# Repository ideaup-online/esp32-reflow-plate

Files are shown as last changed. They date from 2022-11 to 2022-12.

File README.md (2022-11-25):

# Solder Reflow Plate Prototype

This is an ESP32 project for controlling a PCB-based solder reflow plate. The solder reflow plate used in this prototype was made using gerbers from [AfterEarthLTD's solder reflow plate](https://github.com/AfterEarthLTD/Solder-Reflow-Plate).

This project was created out of the need to assemble boards using solder reflow. I have some project ideas involving parts that have footprints that can't be soldered any other way.

I became aware of AfterEarthLTD's design after it was featured in a Great Scott! video on YouTube.

At the time I started this, ATmega328 chips are still not available and the code for the ATmega 4809 revision was not yet completed. So, I decided to send the gerbers for the ATmega 4809 revision to JLCPCB to be manufactured.

## Connecting the Solder Reflow Plate to Breadboard Prototype

The boards were populated with only the mosfet (with associated capacitor and zener diode) and the temp sensor (with associated capacitor). I also simply used a 1nF capacitor for both to reduce the number of parts I needed to purchase.

After that, an XT60 connector was soldered with pigtails to the pads for the barrel connector (I did not use the barrel connector). Leads were soldered for the positive side of the XT60, ground, 5V, the gate of the mosfet, and the output of the temp sensor. The positive side of the XT60 was picked up from the pad for the big capacitor that goes next to the barrel connector. Ground and 5V were picked up from the OLED connector through holes. The lead for the gate of the mosfet was soldered directly to the gate pin/pad of the mosfet (mosfet is installed on board). The temp sensor output was picked up from the ATmega 4809 footprint. The leads were terminated in a dupont connector for ease of breadboarding.

I powered all this from the XT60 using battery power of ~13.5V. That voltage was brought over to a breadboard where the rest of the components and the ESP32 were connected. 3.3V from the ESP32 is sent to the board via the 5V lead. This is fine because the only thing I populated that uses the 5V is the temp sensor and it is just as happy with 3.3V. The ground of the board is connected to the ground of the breadboard components. Finally, the gate and temp sensor voltage are passed to the breadboard via their leads.

The battery voltage is brought down to 5V with an XL4015 buck converter to power the ESP32 dev kit board. The ESP32 dev kit then provides 3.3V to everything else.

## Modifications to AfterEarthLTD's Design

Aside from the obvious of using an ESP32 instead of an ATmega, a couple of changes have been made.

The mosfet would not be turned on all the way by simply connecting the gate to one of the ESP32 GPIOs. The max output of 3.3V would not be sufficient. Therefore a DGD0215 gate driver has been used to drive the mosfet.

Also, the ESP32 ADC is not very linear. So, I opted to use a MAX11645 12-bit ADC and MCP1501-20 voltage reference. The LMT85 temp sensor tops out at around 1.9V on its output, so I chose the MCP1501-20 2.048V reference based on that.

Finally, an LED has been added to show when the heater is on (D1).

## 3D Printed Base

A simple 3D printed base has been created. This keeps the board from burning my desk when it gets hot. The STL file for it is here. It needs 4x M3x12 screws, 2x M3 washers, and 4x M3 nuts to assemble. I printed it in PETG on a Prusa Mini.

## Code

The code is not yet complete. The goal is to have the ability to have the board follow a solder reflow profile reasonably closely while being controlled and monitored via a web app running on the ESP32.

For now, there is a 128x64 OLED display just to monitor temperatures. It displays the value from the LMT85 as well as two K-type thermocouples attached via Adafruit MAX31855 breakout boards.

The current version of the code ensures that everything powers up without the heater coming on. The on-board button for GPIO0 can be used to turn on the heater (heater is only on while the button is pressed).

This readme will be updated as the code evolves.

## Should You Build One?

As of now, I would say no. My goal is to spin a new board based on the changes outlined above. I'd also like to try to make the working surface a bit larger than the current 50x70mm.

All that is going to take a little exploring and experimenting. That said, if you would like to do such exploration on your own, then by all means build this as is!

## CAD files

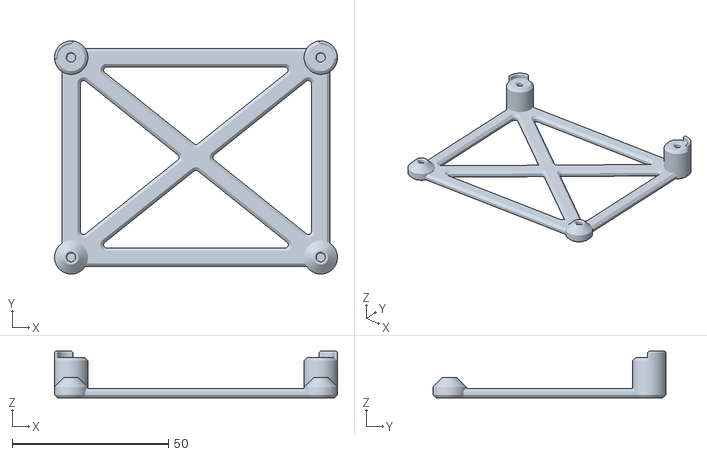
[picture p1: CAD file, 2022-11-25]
solder-reflow-base.stl
90.7 x 74.7 x 15.0

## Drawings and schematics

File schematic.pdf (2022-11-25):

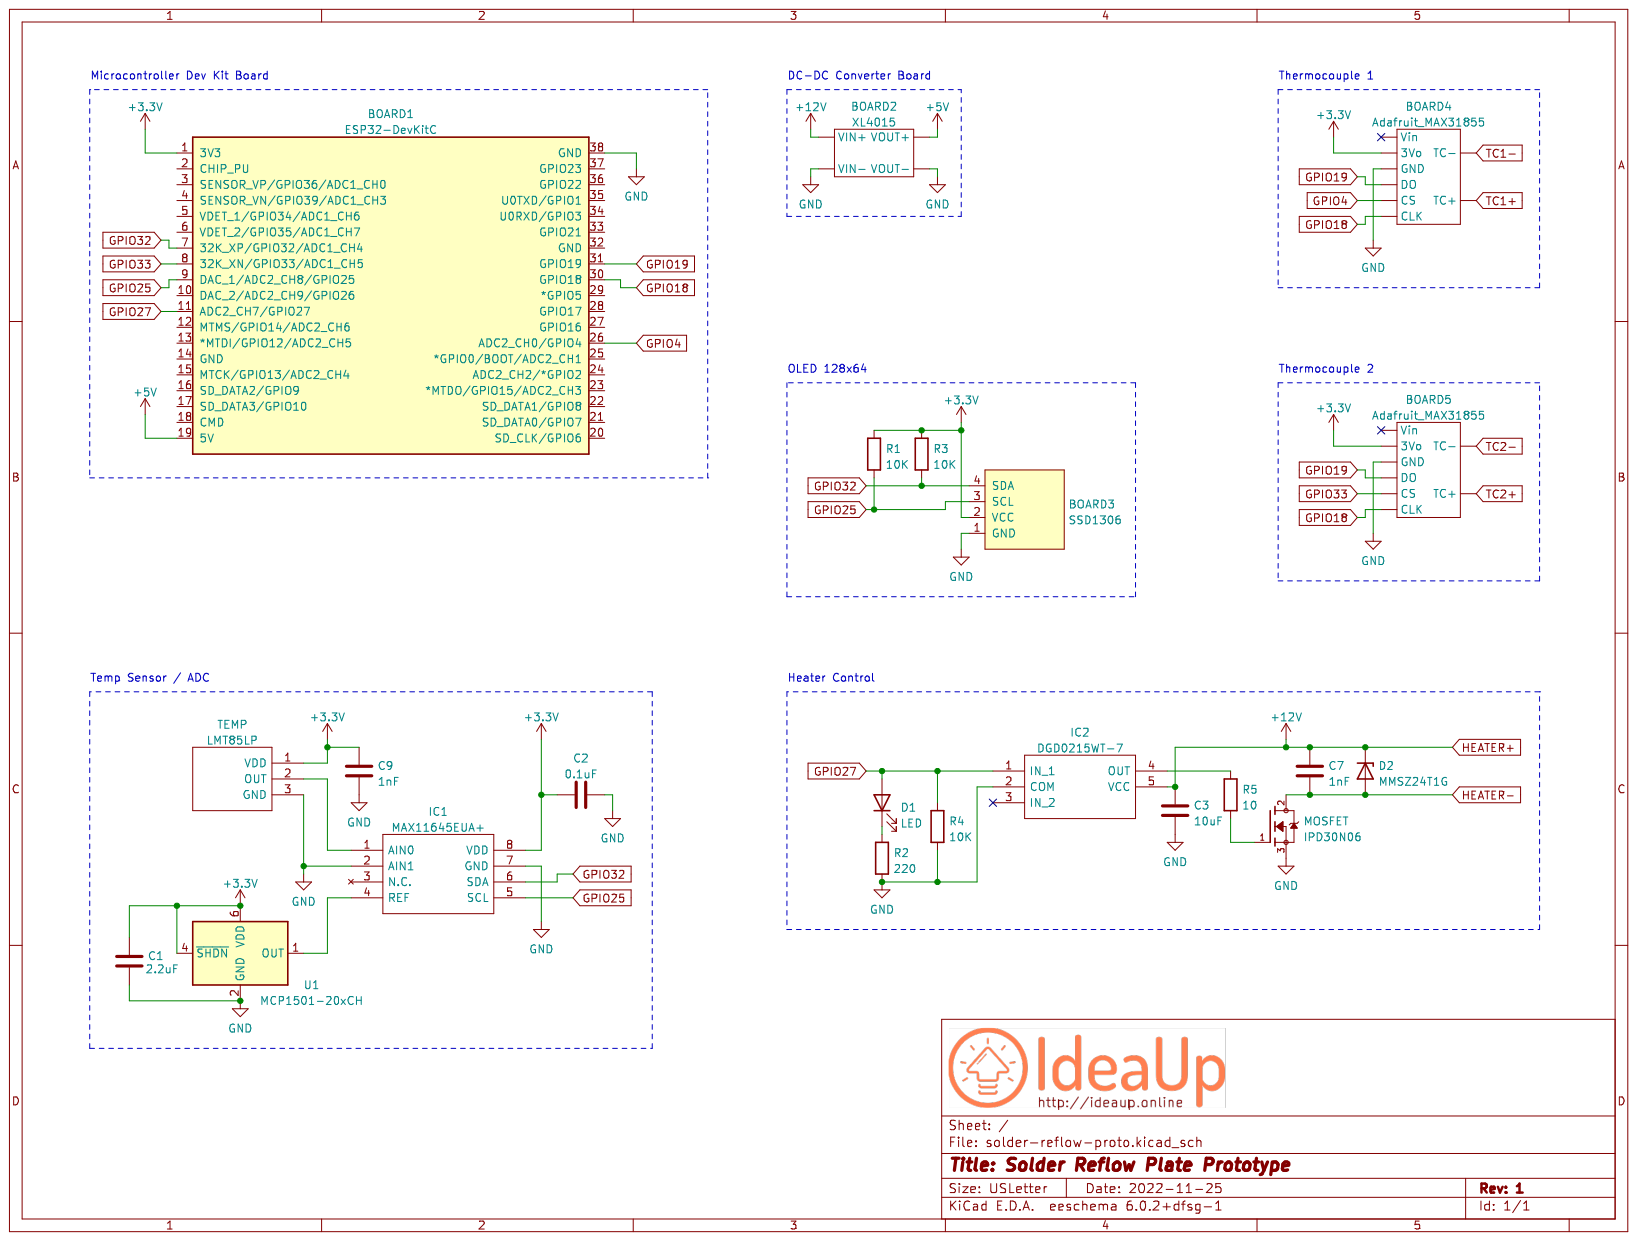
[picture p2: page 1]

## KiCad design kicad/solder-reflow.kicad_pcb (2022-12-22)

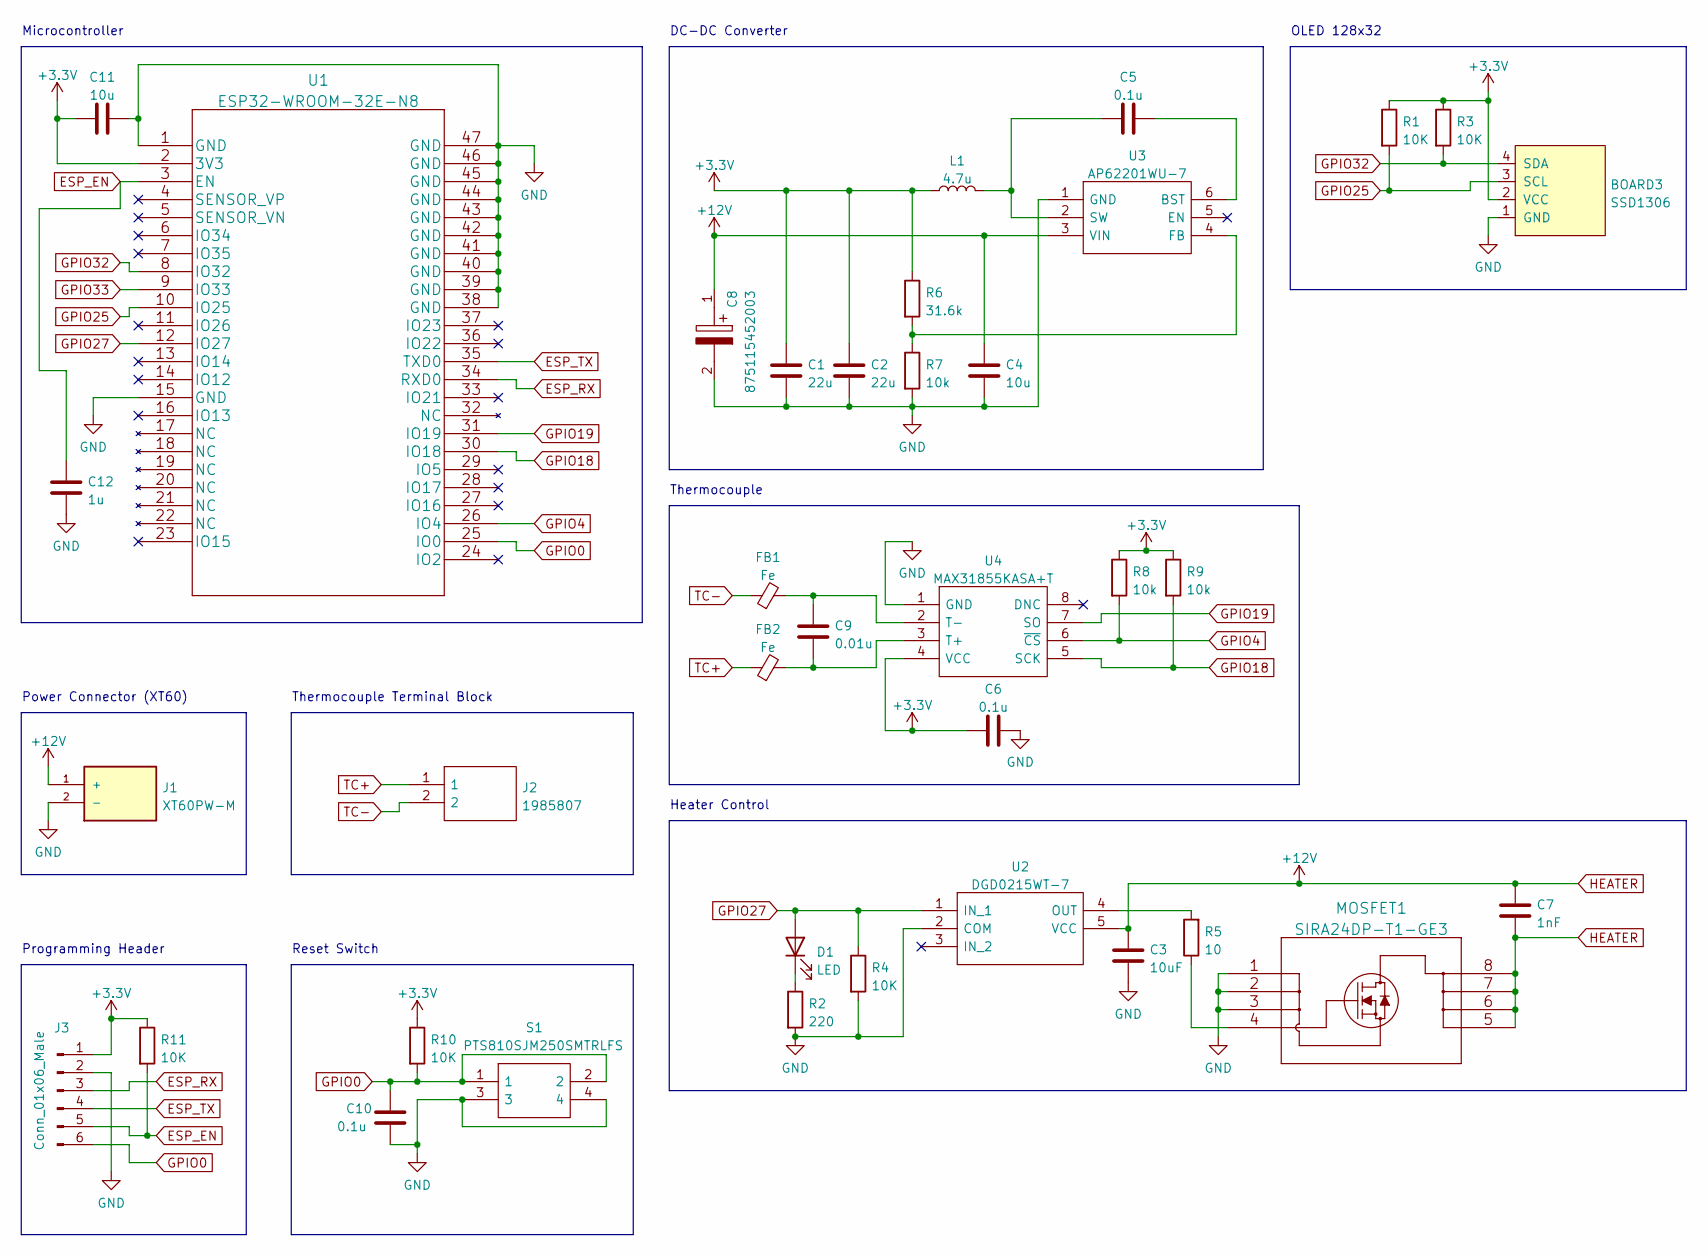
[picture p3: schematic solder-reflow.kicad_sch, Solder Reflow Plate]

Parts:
BOARD3: SSD1306; SSD1306-0.91-OLED-4pin-128x32
C1, C2: 22u; 0805
C3: 10uF; 0603
C4: 10u; 0805
C5, C6, C10: 0.1u; 0603
C7: 1nF; 0603
C8: 875115452003; CAPAE830X870N; Mouser Part Number 710-875115452003
C9: 0.01u; 0603
C11: 10u; 0603
C12: 1u; 0603
D1: LED; LED_0603
FB1, FB2: Fe; 0603
J1: XT60PW-M; AMASS_XT60PW-M; PARTREV V1.2
J2: 1985807; Mouser Part Number 651-1985807
J3: Conn_01x06_Male; PinHeader_1x06_P2.54mm_Vertical
L1: 4.7u; IND_NR6028T4R7M
MOSFET1: SIRA24DP-T1-GE3
R1, R3, R4, R10, R11: 10K; 0603
R2: 220; 0603
R5: 10; 0603
R6: 31.6k; 0603
R7, R8, R9: 10k; 0603
S1: PTS810SJM250SMTRLFS; PTS810SJG250SMTRLFS; Mouser Part Number 611-PTS810SJM250SMTR
U1: ESP32-WROOM-32E-N8
U2: DGD0215WT-7; SOT95P280X110-5N; Mouser Part Number 621-DGD0215WT-7
U3: AP62201WU-7; SOT95P280X100-6N; Mouser Part Number 621-AP62201WU-7
U4: MAX31855KASA+T; SOIC127P600X175-8N; Mouser Part Number 700-MAX31855KASA+T

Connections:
+3V3: BOARD3.2 (VCC), C1.1, C2.1, C6.2, C11.1, J3.1, L1.1, R1.1, R3.1, R6.1, R8.1, R9.1, R10.1, R11.1, U1.2 (3V3), U4.4 (VCC)
ESP_EN: C12.2, J3.5, R11.2, U1.3 (EN)
ESP_RX: J3.3, U1.34 (RXD0)
ESP_TX: J3.4, U1.35 (TXD0)
GND: BOARD3.1 (GND), C1.2, C2.2, C3.2, C4.2, C6.1, C8.2, C10.2, C11.2, C12.1, J1.2 (-), J3.2, MOSFET1.1, MOSFET1.2, MOSFET1.3, R2.2, R4.2, R7.2, S1.3, S1.4, U1.1 (GND), U1.15 (GND), U1.38 (GND), U1.39 (GND), U1.40 (GND), U1.41 (GND), U1.42 (GND), U1.43 (GND), U1.44 (GND), U1.45 (GND), U1.46 (GND), U1.47 (GND), U2.2 (COM), U3.1 (GND), U4.1 (GND)
GPIO0: C10.1, J3.6, R10.2, S1.1, S1.2, U1.25 (IO0)
GPIO4: R8.2, U1.26 (IO4), U4.6 (~CS)
GPIO18: R9.2, U1.30 (IO18), U4.5 (SCK)
GPIO19: U1.31 (IO19), U4.7 (SO)
GPIO25: BOARD3.3 (SCL), R1.2, U1.10 (IO25)
GPIO27: D1.2 (A), R4.1, U1.12 (IO27), U2.1 (IN_1)
GPIO32: BOARD3.4 (SDA), R3.2, U1.8 (IO32)
GPIO33: U1.9 (IO33)
HEATER: C3.1, C4.1, C7.1, C7.2, C8.1, J1.1 (+), MOSFET1.5, MOSFET1.6, MOSFET1.7, MOSFET1.8, U2.5 (VCC), U3.3 (VIN)
unnamed: C5.1, L1.2, U3.2 (SW)
unnamed: C5.2, U3.6 (BST)
unnamed: C9.1, FB1.2, U4.2 (T-)
unnamed: C9.2, FB2.2, U4.3 (T+)
unnamed: D1.1 (K), R2.1
unnamed: MOSFET1.4, R5.1
unnamed: R5.2, U2.4 (OUT)
unnamed: R6.2, R7.1, U3.4 (FB)
TC+: FB2.1, J2.1
TC-: FB1.1, J2.2

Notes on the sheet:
DC-DC Converter
Thermocouple
Heater Control
Reset Switch
Thermocouple Terminal Block
Microcontroller
Power Connector (XT60)
OLED 128x32
Programming Header

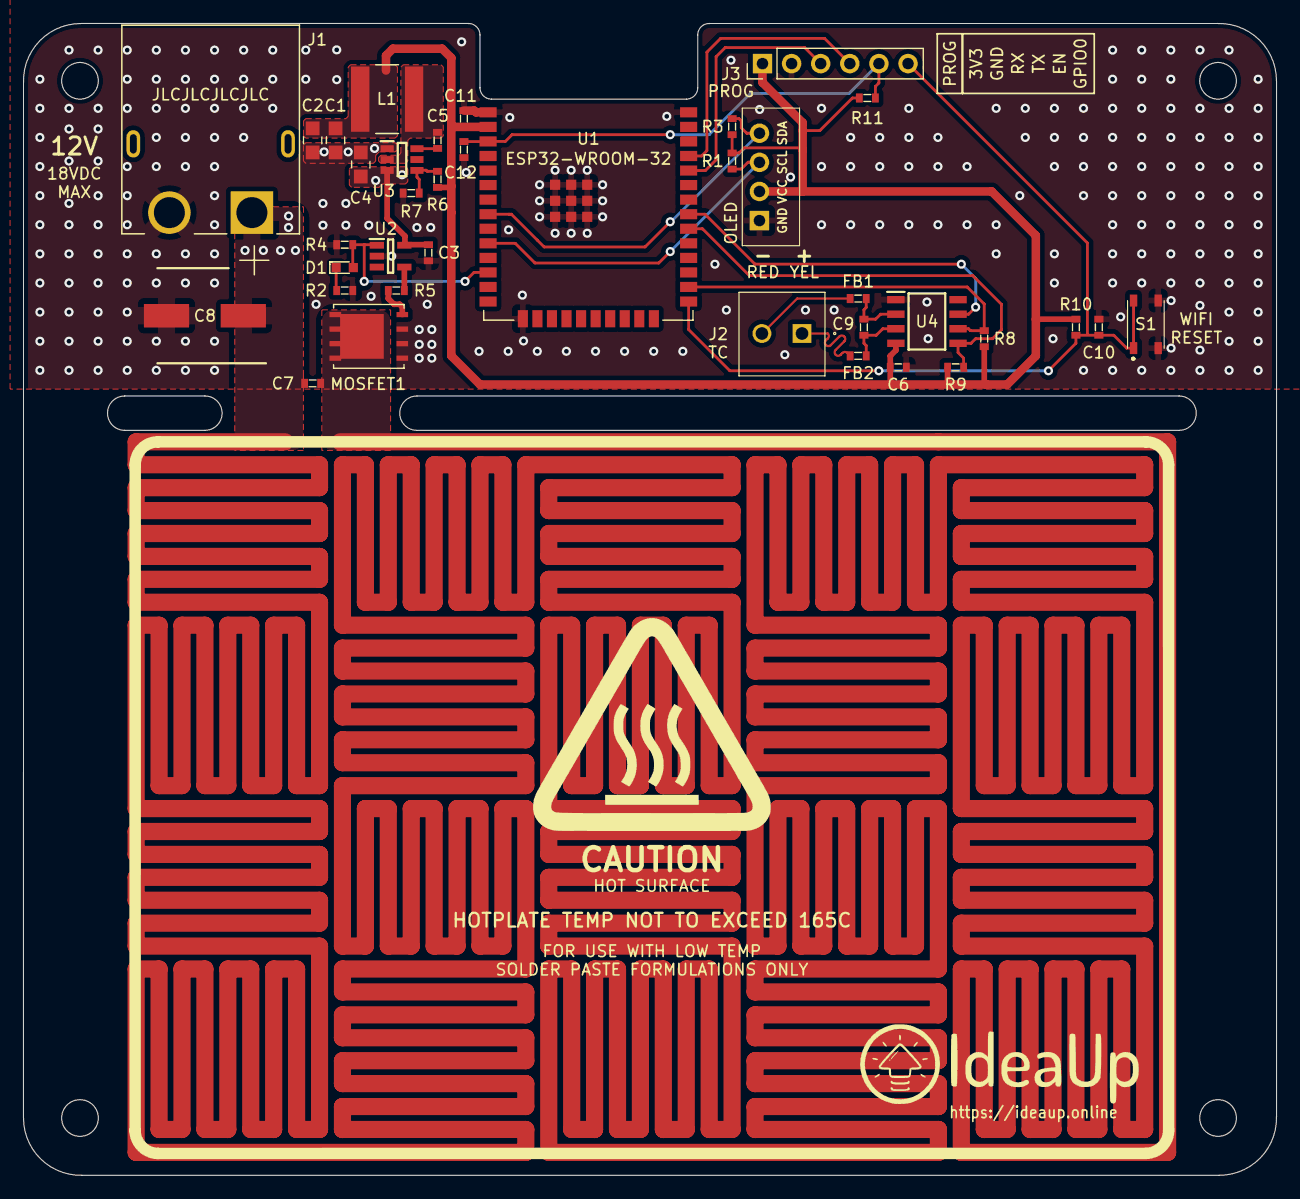
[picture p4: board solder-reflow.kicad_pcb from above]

Board: 2 copper layers, 109.3 x 100.5 mm, 37 parts (0 on the bottom side), 23 nets.

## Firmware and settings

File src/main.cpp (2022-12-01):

#include <Wire.h>
#include <SPI.h>
#include <Adafruit_GFX.h>
#include <Adafruit_SSD1306.h>
#include <PID_v1.h>
#include <WiFi.h>
#include <AsyncTCP.h>
#include <ESPmDNS.h>
#include <ESPAsyncWebServer.h>
#include <Adafruit_MAX31855.h>
#include <LittleFS.h>

#include "config.hpp"
#include "data.hpp"

struct ReflowCurvePoint
{
    int time_ms;
    int temp_c;
};
ReflowCurvePoint chipQuikCurve[] = {
    {0, 25},
    {90000, 90},
    {180000, 130},
    {210000, 138},
    {240000, 165},
    {270000, 138},
    {-1, -1},
};
volatile bool startReflowCurve = false;
volatile bool cancelReflowCurve = false;
bool reflowCurveRunning = false;
unsigned long reflowStartMillis = 0;

// Pin definitions
#define TC_DO_PIN 19
#define TC_CLK_PIN 18
#define TC1_CS_PIN 4
#define TC2_CS_PIN 33

#define FET_PIN 27

#define BTN_PIN 0

#define SDA_PIN 32
#define SCL_PIN 25

// i2c address of ADC
#define ADC_ADDR 0x36

// i2c address of OLED
// and OLED screen size
#define OLED_ADDR 0x3c
#define SCREEN_WIDTH 128
#define SCREEN_HEIGHT 64

// Reads config information from
// a JSON file stored in flash
// (LittleFS)
Config config;

// Object to hold all sensor data
Data data;

// Mutex to serialize access
// to the i2c bus
SemaphoreHandle_t i2cMutex;

// Objects to communicate with
// thermocouple amplifiers
// (MAX31855) via SPI
Adafruit_MAX31855 thermocouple1(TC_CLK_PIN, TC1_CS_PIN, TC_DO_PIN);
Adafruit_MAX31855 thermocouple2(TC_CLK_PIN, TC2_CS_PIN, TC_DO_PIN);

// The delay between each iteration
// of the loop() function. This
// is the sample frequency of the
// PID controller (ms)
const int loopDelay = 100;

// Thermocouple reader task
TaskHandle_t tcTaskHandle;
const int tcNumSamplesToAvg = 4;
const int tcDelay = loopDelay / tcNumSamplesToAvg;

// LMT85 reader task
TaskHandle_t lmt85TaskHandle;
const int lmt85NumSamplesToAvg = 4;
const int lmt85Delay = loopDelay / lmt85NumSamplesToAvg;

// OLED display
Adafruit_SSD1306 display(SCREEN_WIDTH, SCREEN_HEIGHT, &Wire, -1);
TaskHandle_t updateDisplayTaskHandle;
int displayRefreshPeriod = 500;

// GPIO0 button
esp_timer_handle_t btnTimer;
esp_timer_create_args_t btnTimerArgs;
const int debounceTime_us = 25000;
const int lowTemp = 0;
const int highTemp = 150;

// PID controller
volatile double pendingSetpoint = lowTemp;
double Kp = 500.0;
double Ki = 0.625;
double Kd = 1.0;
double pidInput = 0.0;
double pidOutput = 0.0;
double pidSetpoint = 0.0;
PID pid(&pidInput, &pidOutput, &pidSetpoint, Kp, Ki, Kd, DIRECT);

// setting PWM properties
const int freq = 15;
const int ledChannel = 0;
const int resolution = 12;

// CSV server
const int csvServerPort = 2112;
TaskHandle_t csvServerTaskHandle;
const int csvReportingDelay = loopDelay;
struct Connection
{
    WiFiClient client;
    unsigned long zeroMillis;
};

// Prototypes
double c2f(double celsius);
void readThermocouples(void *);
void readLMT85(void *);
void updateDisplay(void *);
void csvServer(void *);
void IRAM_ATTR btnHandler();
void IRAM_ATTR btnDebounce(void *);
double getLMT85Temp(int lmt85_mV);

void setup()
{
    Serial.begin(115200);

    // Give the serial monitor a couple of
    // seconds to start up
    delay(2000);

    Serial.println("Solder Reflow Plate Controller V1.0");

    // Set up heater pin and ensure
    // heater is off to start
    Serial.printf("Initializing heater to off...");
    pinMode(FET_PIN, OUTPUT);
    digitalWrite(FET_PIN, LOW);
    if (ledcSetup(ledChannel, freq, resolution) == 0)
    {
        Serial.printf("ledcSetup failed!");
        while (true)
        {
            delay(10);
        }
    }
    ledcAttachPin(FET_PIN, ledChannel);
    ledcWrite(ledChannel, pidOutput);
    Serial.printf("done.\n");

    // Start LittleFS
    Serial.printf("Initializing LittleFS...");
    if (!LittleFS.begin())
    {
        Serial.printf("failed\n");
        while (true)
        {
            delay(10);
        }
    }
    else
    {
        Serial.printf("done.\n");
    }

    // Open config file for reading
    Serial.printf("Opening config file...");
    File configFile = LittleFS.open("/config.json", "r");
    if (!configFile)
    {
        Serial.printf("failed\n");
        while (true)
        {
            delay(10);
        }
    }
    else
    {
        Serial.printf("done.\n");
    }

    // Read config file into config object
    Serial.printf("Reading config file...");
    if (!config.readConfig(configFile))
    {
        Serial.printf("failed\n");
        while (true)
        {
            delay(10);
        }
    }
    else
    {
        configFile.close();
        Serial.printf("done.\n");
    }

    WiFi.begin(config.getSSID(), config.getKey());

    Serial.printf("Connecting to WiFi...");
    while (WiFi.status() != WL_CONNECTED)
    {
        delay(1000);
    }
    Serial.printf("done.\n");

    IPAddress localAddr = WiFi.localIP();
    Serial.printf("IP: %s\n", localAddr.toString().c_str());

    if (!MDNS.begin(config.getMDNS()))
    {
        Serial.println("Error setting up mDNS responder");
    }
    else
    {
        Serial.printf("mDNS: %s\n", config.getMDNS());
    }

    Serial.printf("Initializing thermocouple 1...");
    if (!thermocouple1.begin())
    {
        Serial.println("ERROR.");
        while (true)
        {
            delay(10);
        }
    }
    Serial.printf("done.\n");

    Serial.printf("Initializing thermocouple 2...");
    if (!thermocouple2.begin())
    {
        Serial.println("ERROR.");
        while (true)
        {
            delay(10);
        }
    }
    Serial.printf("done.\n");

    // Start thermocouple reader task
    if (xTaskCreate(readThermocouples,
                    "Read TCs",
                    1024,
                    0,
                    1,
                    &tcTaskHandle) == pdPASS)
    {
        Serial.println("Thermocouple task started");
    }
    else
    {
        Serial.println("Failed to start thermocouple task");
        while (true)
        {
            delay(10);
        }
    }

    Serial.printf("Initializing OLED...");
    Wire.setPins(SDA_PIN, SCL_PIN);
    if (!display.begin(SSD1306_SWITCHCAPVCC, 0x3C))
    {
        Serial.println("SSD1306 allocation failed");
        while (1)
            delay(10);
    }
    Serial.printf("done.\n");

    // Set up ADC (MAX11645)
    Serial.printf("Initializing external ADC...");
    Wire.begin();
    Wire.beginTransmission((uint16_t)ADC_ADDR);
    Wire.write((uint8_t)0b10100000);
    Wire.write((uint8_t)0b01100001);
    Wire.endTransmission();
    Serial.printf("done.\n");

    display.clearDisplay();
    display.setTextSize(1);
    display.setTextColor(SSD1306_WHITE);
    display.display();

    // Create the i2c mutex
    i2cMutex = xSemaphoreCreateMutex();

    // Start lmt85 reader task
    if (xTaskCreate(readLMT85,
                    "Read LMT85",
                    2048,
                    &i2cMutex,
                    1,
                    &lmt85TaskHandle) == pdPASS)
    {
        Serial.println("LMT85 reader task started");
    }
    else
    {
        Serial.println("Failed to start LMT85 reader task");
        while (true)
        {
            delay(10);
        }
    }

    // Start display update task
    if (xTaskCreate(updateDisplay,
                    "Display Update",
                    4096,
                    &i2cMutex,
                    1,
                    &updateDisplayTaskHandle) == pdPASS)
    {
        Serial.println("display update task started");
    }
    else
    {
        Serial.println("Failed to start display update task");
        while (true)
        {
            delay(10);
        }
    }

    // Set up on board GPIO0 button
    // Note that its interrupt will
    // be attached in btnDebounce()
    // after a 2 second timer
    // expires
    pinMode(BTN_PIN, INPUT);
    btnTimerArgs.callback = btnDebounce;
    if (esp_timer_create(&btnTimerArgs, &btnTimer) != ESP_OK)
    {
        Serial.println("Failed to create esp timer for button debouncing");
        while (true)
        {
            delay(10);
        }
    }
    esp_timer_start_once(btnTimer, 2000);

    // Start CSV server task
    if (xTaskCreate(csvServer,
                    "CSV Server",
                    4096,
                    &i2cMutex,
                    1,
                    &csvServerTaskHandle) == pdPASS)
    {
        Serial.println("CSV server task started");
    }
    else
    {
        Serial.println("Failed to start CSV server task");
        while (true)
        {
            delay(10);
        }
    }

    // Set PID output limits based on
    // PWM resolution, sample time based on
    // loop delay time, and automatic mode
    int maxForResolution = (1 << resolution) - 1;
    Serial.printf("resolution: %d maxLimit: %d\n", resolution, maxForResolution);
    pid.SetOutputLimits(0, maxForResolution);
    pid.SetSampleTime(loopDelay);
    pid.SetMode(AUTOMATIC);
}

void loop()
{
    if (reflowCurveRunning)
    {
        if (cancelReflowCurve)
        {
            cancelReflowCurve = false;
            reflowCurveRunning = false;
            data.setSetpoint(0.0);
            Serial.println("Canceling reflow curve");
        }
        else
        {
            unsigned long curveTime = millis() - reflowStartMillis;
            double newSetpoint = 0.0;
            for (int i = 0; chipQuikCurve[i].time_ms != -1; i++)
            {
                if (curveTime < chipQuikCurve[i].time_ms)
                {
                    if (i > 0)
                    {
                        double timePct = (double)(curveTime - chipQuikCurve[i - 1].time_ms) /
                                         (double)(chipQuikCurve[i].time_ms - chipQuikCurve[i - 1].time_ms);
                        newSetpoint = chipQuikCurve[i - 1].temp_c +
                                      ((chipQuikCurve[i].temp_c - chipQuikCurve[i - 1].temp_c) * timePct);
                        break;
                    }
                }
            }
            data.setSetpoint(newSetpoint);
            if (newSetpoint == 0.0)
            {
                reflowCurveRunning = false;
                Serial.println("Reflow curve completed");
            }
        }
    }
    else
    {
        if (startReflowCurve)
        {
            startReflowCurve = false;
            reflowCurveRunning = true;
            reflowStartMillis = millis();
            Serial.println("Starting reflow curve");
        }
    }

    // Compute output power based on TC1
    // input and apply it
    pidInput = data.getTc1Temp();
    pidSetpoint = data.getSetpoint();
    pid.Compute();
    ledcWrite(ledChannel, pidOutput);

    delay(loopDelay);
}

double c2f(double celsius)
{
    return (celsius * (9.0 / 5.0)) + 32;
}

void readThermocouples(void *)
{
    double c;
    double tc1Samples[tcNumSamplesToAvg];
    double tc2Samples[tcNumSamplesToAvg];
    int sampleIdx = 0;
    int count = 0;

    while (true)
    {
        // Read TC1 input
        c = thermocouple1.readCelsius();
        if (isnan(c))
        {
            Serial.println("Thermocouple 1 fault(s) detected!");
            uint8_t e = thermocouple1.readError();
            if (e & MAX31855_FAULT_OPEN)
            {
                Serial.println("FAULT: Thermocouple is open - no connections.");
            }
            if (e & MAX31855_FAULT_SHORT_GND)
            {
                Serial.println("FAULT: Thermocouple is short-circuited to GND.");
            }
            if (e & MAX31855_FAULT_SHORT_VCC)
            {
                Serial.println("FAULT: Thermocouple is short-circuited to VCC.");
            }
        }
        else
        {
            tc1Samples[sampleIdx] = c;

            if (count == tcNumSamplesToAvg)
            {
                double sum = 0.0;
                for (int i = 0; i < tcNumSamplesToAvg; i++)
                {
                    sum += tc1Samples[i];
                }

                double avg = sum / tcNumSamplesToAvg;
                data.setTc1Temp(avg);
            }
        }

        // Read TC2 input
        c = thermocouple2.readCelsius();
        if (isnan(c))
        {
            Serial.println("Thermocouple 2 fault(s) detected!");
            uint8_t e = thermocouple1.readError();
            if (e & MAX31855_FAULT_OPEN)
            {
                Serial.println("FAULT: Thermocouple is open - no connections.");
            }
            if (e & MAX31855_FAULT_SHORT_GND)
            {
                Serial.println("FAULT: Thermocouple is short-circuited to GND.");
            }
            if (e & MAX31855_FAULT_SHORT_VCC)
            {
                Serial.println("FAULT: Thermocouple is short-circuited to VCC.");
            }
        }
        else
        {
            tc2Samples[sampleIdx] = c;

            if (count == tcNumSamplesToAvg)
            {
                double sum = 0.0;
                for (int i = 0; i < tcNumSamplesToAvg; i++)
                {
                    sum += tc2Samples[i];
                }

                double avg = sum / tcNumSamplesToAvg;
                data.setTc2Temp(avg);
            }
        }

        // Update count until we have
        // enough samples to start averaging
        if (count < tcNumSamplesToAvg)
        {
            count++;
        }

        // Update sampleIdx
        sampleIdx = (sampleIdx + 1) % tcNumSamplesToAvg;

        // Wait for next sample interval
        vTaskDelay(tcDelay / portTICK_PERIOD_MS);
    }
}

void readLMT85(void *)
{
    double c;
    double samples[lmt85NumSamplesToAvg];
    int sampleIdx = 0;
    int count = 0;

    while (true)
    {
        // Read the value of the LMT85
        uint16_t lmt85Counts = 0;

        // Take the mutex
        xSemaphoreTake(i2cMutex, portMAX_DELAY);

        // Request 2 bytes from the external ADC
        uint8_t bytesReceived = Wire.requestFrom(ADC_ADDR, 2);
        if (bytesReceived == 2)
        {
            uint8_t tmp[2];
            Wire.readBytes(tmp, 2);
            lmt85Counts = ((tmp[0] << 8) | tmp[1]) & 0x0fff;
        }

        // Give the mutex back
        xSemaphoreGive(i2cMutex);

        // Voltage reference is 2.048V, ADC is 12-bit
        // (4096 counts); thus, each count represents
        // 0.5mV
        int tmp = lmt85Counts / 2;
        samples[sampleIdx] = tmp;

        if (count == lmt85NumSamplesToAvg)
        {
            int sum = 0.0;
            for (int i = 0; i < tcNumSamplesToAvg; i++)
            {
                sum += samples[i];
            }

            int avg = sum / lmt85NumSamplesToAvg;
            data.setLmt85_mV(avg);
        }

        // Update count until we have
        // enough samples to start averaging
        if (count < lmt85NumSamplesToAvg)
        {
            count++;
        }

        // Update sampleIdx
        sampleIdx = (sampleIdx + 1) % lmt85NumSamplesToAvg;

        // Wait for next sample interval
        vTaskDelay(lmt85Delay / portTICK_PERIOD_MS);
    }
}

void updateDisplay(void *)
{
    const int tc1TempX = 0;
    const int tc1TempY = 1;
    const int tc1TempWidth = SCREEN_WIDTH;
    const int tc1TempHeight = 8;
    const int tc2TempX = 0;
    const int tc2TempY = 11;
    const int tc2TempWidth = SCREEN_WIDTH;
    const int tc2TempHeight = 8;
    const int lmt85X = 0;
    const int lmt85Y = 21;
    const int lmt85Width = SCREEN_WIDTH;
    const int lmt85Height = 8;
    const int setpointX = 0;
    const int setpointY = 31;
    const int setpointWidth = SCREEN_WIDTH;
    const int setpointHeight = 8;

    double currentTc1TempC = -1.0;
    double currentTc2TempC = -1.0;
    int currentLmt85_mV = -1;
    double currentSetpoint = -1.0;
    bool displayNeedsRefresh = false;

    while (true)
    {
        // TC1
        double tmp = data.getTc1Temp();
        if (tmp != currentTc1TempC)
        {
            currentTc1TempC = tmp;

            display.fillRect(tc1TempX, tc1TempY, tc1TempWidth, tc1TempHeight, SSD1306_BLACK);
            display.setCursor(tc1TempX, tc1TempY);
            display.printf("T1: %6.2f C %6.2f F", currentTc1TempC, c2f(currentTc1TempC));

            displayNeedsRefresh = true;
        }

        // TC2
        tmp = data.getTc2Temp();
        if (tmp != currentTc2TempC)
        {
            currentTc2TempC = tmp;

            display.fillRect(tc2TempX, tc2TempY, tc2TempWidth, tc2TempHeight, SSD1306_BLACK);
            display.setCursor(tc2TempX, tc2TempY);
            display.printf("T2: %6.2f C %6.2f F", currentTc2TempC, c2f(currentTc2TempC));

            displayNeedsRefresh = true;
        }

        // LMT85
        int tmp2 = data.getLmt85_mV();
        if (tmp2 != currentLmt85_mV)
        {
            currentLmt85_mV = tmp2;

            // Look up temp for this voltage
            double c = getLMT85Temp(currentLmt85_mV);

            display.fillRect(lmt85X, lmt85Y, lmt85Width, lmt85Height, SSD1306_BLACK);
            display.setCursor(lmt85X, lmt85Y);
            display.printf("LM: %6.2f C %6.2f F", c, c2f(c));

            displayNeedsRefresh = true;
        }

        // Set point
        tmp = data.getSetpoint();
        if (tmp != currentSetpoint)
        {
            currentSetpoint = tmp;

            display.fillRect(setpointX, setpointY, setpointWidth, setpointHeight, SSD1306_BLACK);
            display.setCursor(setpointX, setpointY);
            display.printf("SP: %6.2f C %6.2f F", currentSetpoint, c2f(currentSetpoint));

            displayNeedsRefresh = true;
        }

        // Actually update the display if anything
        // has changed
        if (displayNeedsRefresh)
        {
            displayNeedsRefresh = false;

            // Take the semaphore
            xSemaphoreTake(i2cMutex, portMAX_DELAY);

            // Send updates to display via i2c
            display.display();

            // Give the mutex back
            xSemaphoreGive(i2cMutex);
        }

        // Wait for the next refresh interval
        vTaskDelay(displayRefreshPeriod / portTICK_PERIOD_MS);
    }
}

void csvServer(void *)
{
    // Accept up to 10 connections
    const int maxConns = 10;
    Connection conns[maxConns];

    // Create a server object
    WiFiServer server(csvServerPort);

    // Start server
    server.begin();

    while (true)
    {
        unsigned long loopStart = millis();

        // Handle new connections
        while (server.hasClient())
        {
            bool connectionAccepted = false;
            for (int i = 0; i < maxConns; i++)
            {
                if (!conns[i].client.connected())
                {
                    // Accept connection
                    conns[i].client = server.available();
                    conns[i].zeroMillis = loopStart;

                    // Send CSV headers
                    conns[i].client.printf("Time,\"Set Point\",\"Under Heater\",\"Target Board\",\"Built-In Temp\",\"PID Output\",\"Kp=%0.2f Ki=%0.2f Kd=%0.2f\"\n",
                                           Kp, Ki, Kd);

                    // Set flag
                    connectionAccepted = true;
                }
            }

            if (!connectionAccepted)
            {
                // No slots left; reject
                // connection
                server.available().stop();
            }
        }

        // Send CSV data to connected
        // clients
        for (int i = 0; i < maxConns; i++)
        {
            if (conns[i].client.connected())
            {
                unsigned long reportTime = loopStart - conns[i].zeroMillis;
                conns[i].client.printf("%0.2f,%0.2f,%0.2f,%0.2f,%0.2f,%0.2f\n",
                                       (double)reportTime / 1000.0,
                                       data.getSetpoint(),
                                       data.getTc1Temp(),
                                       data.getTc2Temp(),
                                       getLMT85Temp(data.getLmt85_mV()),
                                       pidOutput / 40.95);
            }
        }

        // Wait for next reporting interval
        int delay = csvReportingDelay - (millis() - loopStart);
        if (delay > 0)
        {
            vTaskDelay(delay / portTICK_PERIOD_MS);
        }
    }
}

void IRAM_ATTR btnHandler()
{
    // Software switch debounce:
    // detach interrupt and start a
    // timer to re-attach it after
    // debounceTime_us microseconds
    detachInterrupt(BTN_PIN);
    esp_timer_start_once(btnTimer, debounceTime_us);

    // Start or cancel the reflow curve
    if (!reflowCurveRunning)
    {
        startReflowCurve = true;
    }
    else
    {
        cancelReflowCurve = true;
    }
}

void IRAM_ATTR btnDebounce(void *)
{
    if (digitalRead(BTN_PIN) == HIGH)
    {
        attachInterrupt(BTN_PIN, btnHandler, FALLING);
    }
    else
    {
        esp_timer_start_once(btnTimer, debounceTime_us);
    }
}
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

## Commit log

2022-11-25 Fixed typo in schematic
2022-11-28 Added PID controller; did initial tune
2022-12-01 Added tcp server to serve csv data; found good PID values; started changes to follow reflow curve
2022-12-01 Tweaked PID values
2022-12-21 Added KiCad project for esp32-based PCB
    [solder-reflow.kicad_pcb, solder-reflow.kicad_sch]
2022-12-22 Tweaked layout; refined buck layout; added graphics
    [solder-reflow.kicad_pcb, solder-reflow.kicad_sch]
2022-12-22 Changed tactile switch part
    [solder-reflow.kicad_pcb, solder-reflow.kicad_sch]

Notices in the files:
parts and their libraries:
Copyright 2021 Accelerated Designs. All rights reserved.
